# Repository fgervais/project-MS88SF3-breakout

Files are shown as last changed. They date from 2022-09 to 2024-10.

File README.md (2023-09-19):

# MS88SF3 Breakout Board

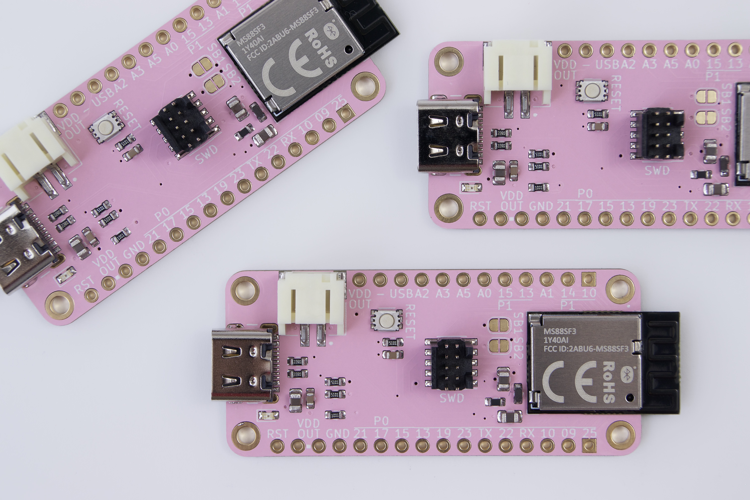
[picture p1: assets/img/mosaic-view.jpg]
Overview

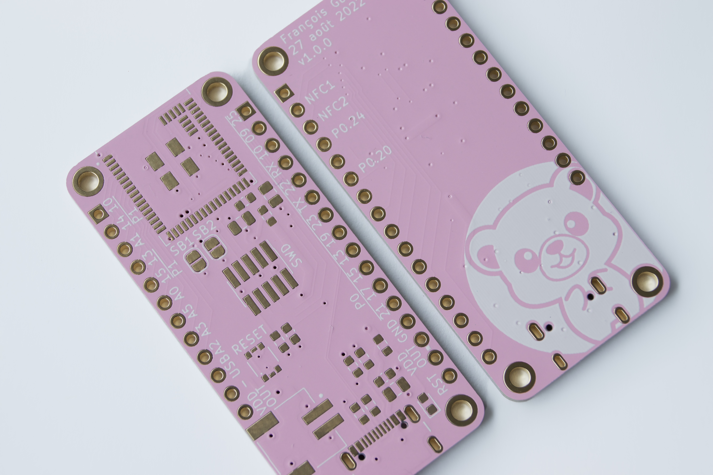
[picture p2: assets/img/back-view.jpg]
PCB


## Objective

Try out the nRF52840 module from Minew.

## Power Consumption

### Sleep - Full RAM retention - GPIO wake-up

Average: 2.78 μA

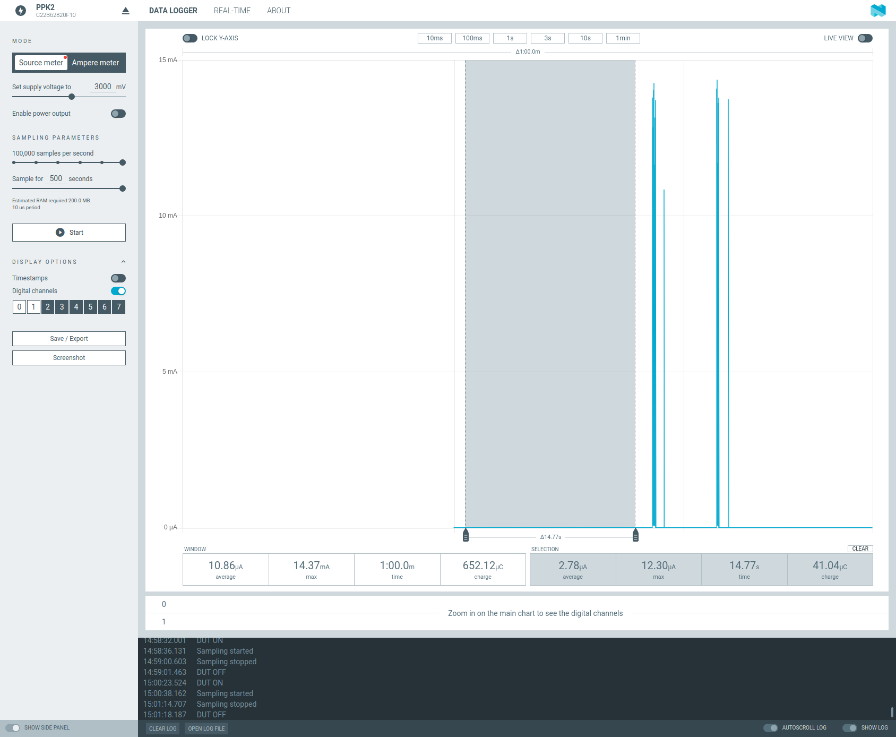
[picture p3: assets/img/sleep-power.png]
Sleep Power


## Price

## PCB

## BOM

### Firmware

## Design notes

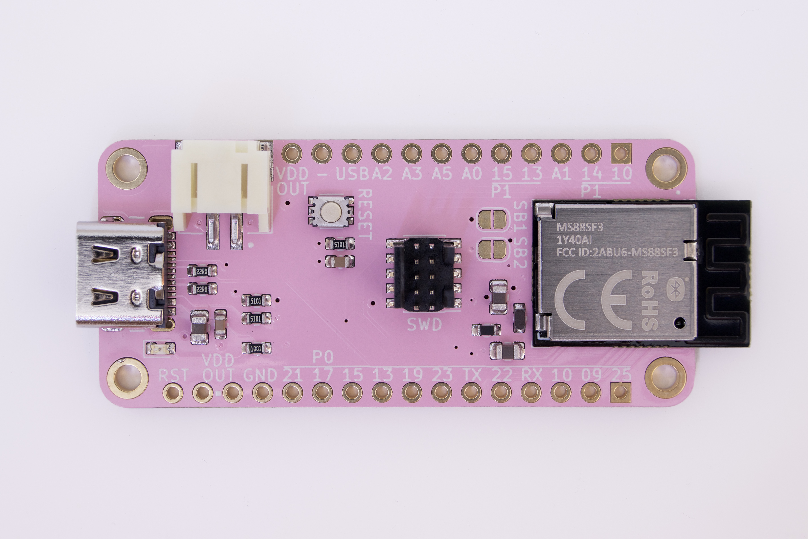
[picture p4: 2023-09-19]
assets/img/single-top-view.jpg

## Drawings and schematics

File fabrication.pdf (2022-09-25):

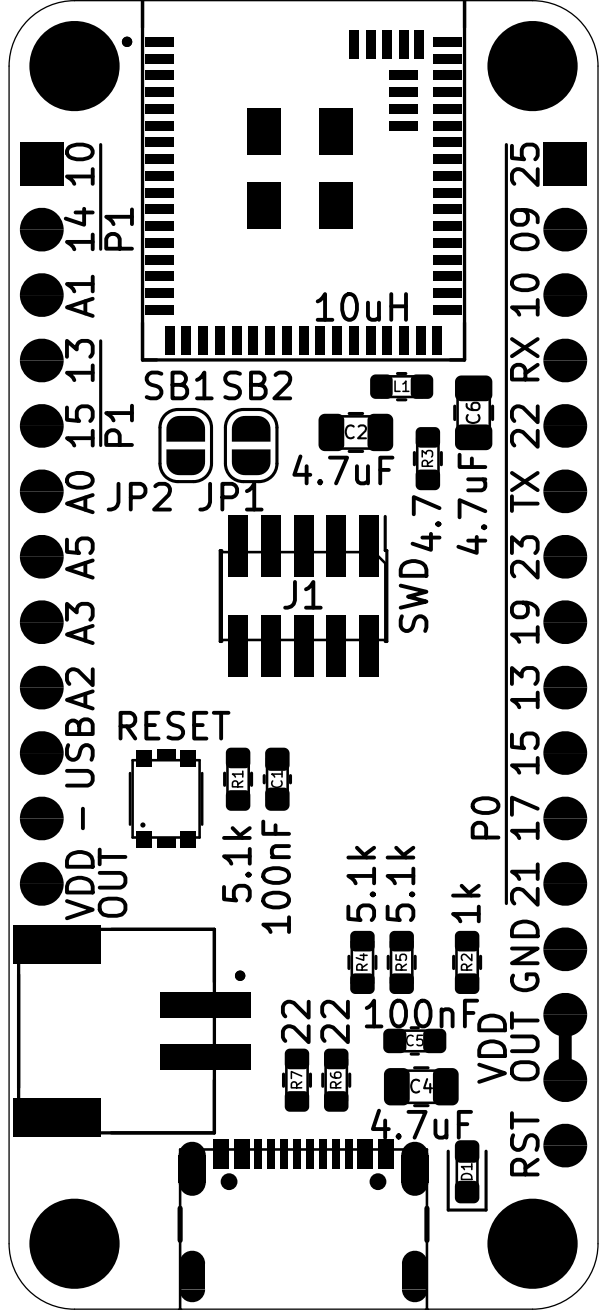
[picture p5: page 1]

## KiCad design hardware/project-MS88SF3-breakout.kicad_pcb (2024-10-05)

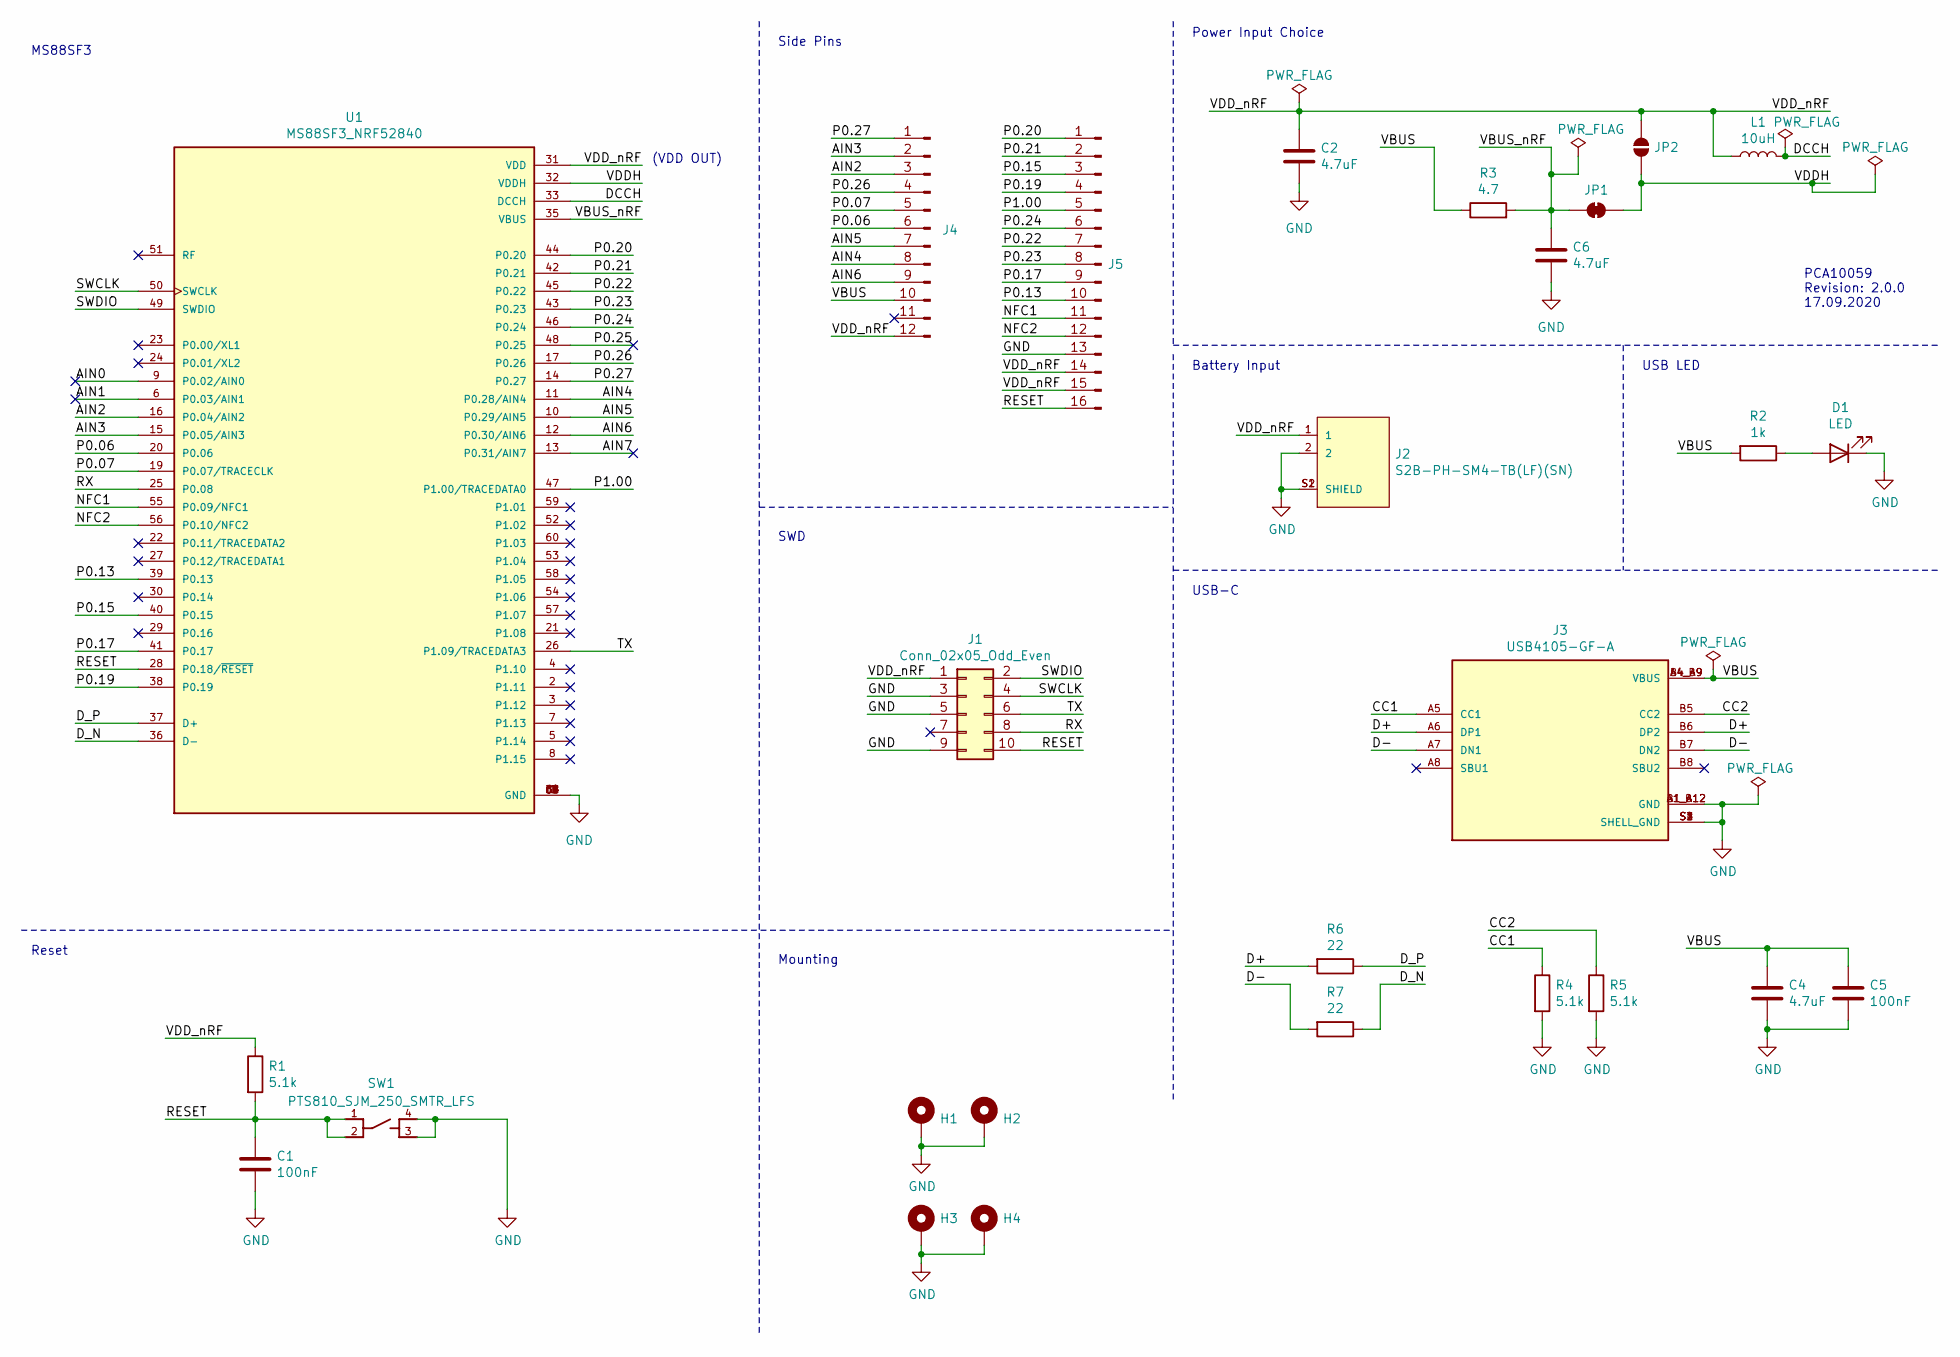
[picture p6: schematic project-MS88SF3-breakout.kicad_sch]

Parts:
C1, C5: 100nF; C_0603_1608Metric
C2, C4, C6: 4.7uF; C_0805_2012Metric
D1: LED; LED_0603_1608Metric
H1, H2, H3, H4: MountingHole_Pad; MountingHole_2.2mm_M2_ISO7380_Pad
J1: Conn_02x05_Odd_Even; PinHeader_2x05_P1.27mm_Vertical_SMD
J2: S2B-PH-SM4-TB(LF)(SN); JST_S2B-PH-SM4-TB(LF)(SN)
J3: USB4105-GF-A; GCT_USB4105-GF-A; PARTREV A3
J4: Conn_01x12_Pin; PinHeader_1x12_P2.54mm_Vertical
J5: Conn_01x16_Pin; PinHeader_1x16_P2.54mm_Vertical
JP1: SolderJumper_2_Bridged; SolderJumper-2_P1.3mm_Bridged_RoundedPad1.0x1.5mm
JP2: SolderJumper_2_Open; SolderJumper-2_P1.3mm_Open_RoundedPad1.0x1.5mm
L1: 10uH; L_0603_1608Metric
R1, R4, R5: 5.1k; R_0603_1608Metric
R2: 1k; R_0603_1608Metric
R3: 4.7; R_0603_1608Metric
R6, R7: 22; R_0603_1608Metric
SW1: PTS810_SJM_250_SMTR_LFS; SW_PTS810_SJM_250_SMTR_LFS; DigiKey_Part_Number CKN10502TR-ND
U1: MS88SF3_NRF52840; MODULE_MS88SF3_NRF52840; PARTREV V1.1

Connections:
/AIN0: U1.9 (P0.02/AIN0)
/AIN1: U1.6 (P0.03/AIN1)
/AIN2: J4.3, U1.16 (P0.04/AIN2)
/AIN3: J4.2, U1.15 (P0.05/AIN3)
/AIN4: J4.8, U1.11 (P0.28/AIN4)
/AIN5: J4.7, U1.10 (P0.29/AIN5)
/AIN6: J4.9, U1.12 (P0.30/AIN6)
/AIN7: U1.13 (P0.31/AIN7)
/CC1: J3.A5 (CC1), R4.1
/CC2: J3.B5 (CC2), R5.1
/D+: J3.A6 (DP1), J3.B6 (DP2), R6.2
/D-: J3.A7 (DN1), J3.B7 (DN2), R7.2
/DCCH: L1.2, U1.33 (DCCH)
/D_N: R7.1, U1.36 (D-)
/D_P: R6.1, U1.37 (D+)
/NFC1: J5.11, U1.55 (P0.09/NFC1)
/NFC2: J5.12, U1.56 (P0.10/NFC2)
/P0.06: J4.6, U1.20 (P0.06)
/P0.07: J4.5, U1.19 (P0.07/TRACECLK)
/P0.13: J5.10, U1.39 (P0.13)
/P0.15: J5.3, U1.40 (P0.15)
/P0.17: J5.9, U1.41 (P0.17)
/P0.19: J5.4, U1.38 (P0.19)
/P0.20: J5.1, U1.44 (P0.20)
/P0.21: J5.2, U1.42 (P0.21)
/P0.22: J5.7, U1.45 (P0.22)
/P0.23: J5.8, U1.43 (P0.23)
/P0.24: J5.6, U1.46 (P0.24)
/P0.25: U1.48 (P0.25)
/P0.26: J4.4, U1.17 (P0.26)
/P0.27: J4.1, U1.14 (P0.27)
/P1.00: J5.5, U1.47 (P1.00/TRACEDATA0)
/RESET: C1.1, J1.10, J5.16, R1.2, SW1.1, SW1.2, U1.28 (P0.18/~RESET)
/RX: J1.8, U1.25 (P0.08)
/SWCLK: J1.4, U1.50 (SWCLK)
/SWDIO: J1.2, U1.49 (SWDIO)
/TX: J1.6, U1.26 (P1.09/TRACEDATA3)
/VBUS: C4.1, C5.1, J3.A4_B9 (VBUS), J3.B4_A9 (VBUS), J4.10, R2.2, R3.1
/VBUS_nRF: C6.1, JP1.1 (A), R3.2, U1.35 (VBUS)
/VDDH: JP1.2 (B), JP2.2 (B), U1.32 (VDDH)
/VDD_nRF: C2.1, J1.1, J2.1, J4.12, J5.14, J5.15, JP2.1 (A), L1.1, R1.1, U1.31 (VDD)
GND: C1.2, C2.2, C4.2, C5.2, C6.2, D1.1 (K), H1.1, H2.1, H3.1, H4.1, J1.3, J1.5, J1.9, J2.2, J2.S1 (SHIELD), J2.S2 (SHIELD), J3.A1_B12 (GND), J3.B1_A12 (GND), J3.S1 (SHELL_GND), J3.S2 (SHELL_GND), J3.S3 (SHELL_GND), J3.S4 (SHELL_GND), J5.13, R4.2, R5.2, SW1.3, SW1.4, U1.1 (GND), U1.18 (GND), U1.34 (GND), U1.61 (GND), U1.62 (GND), U1.63 (GND), U1.64 (GND)
unnamed: D1.2 (A), R2.1

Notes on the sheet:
USB LED
Side Pins
SWD
Mounting
PCA10059 Revision: 2.0.0 17.09.2020
Power Input Choice
Battery Input
Reset
USB-C
(VDD OUT)
MS88SF3

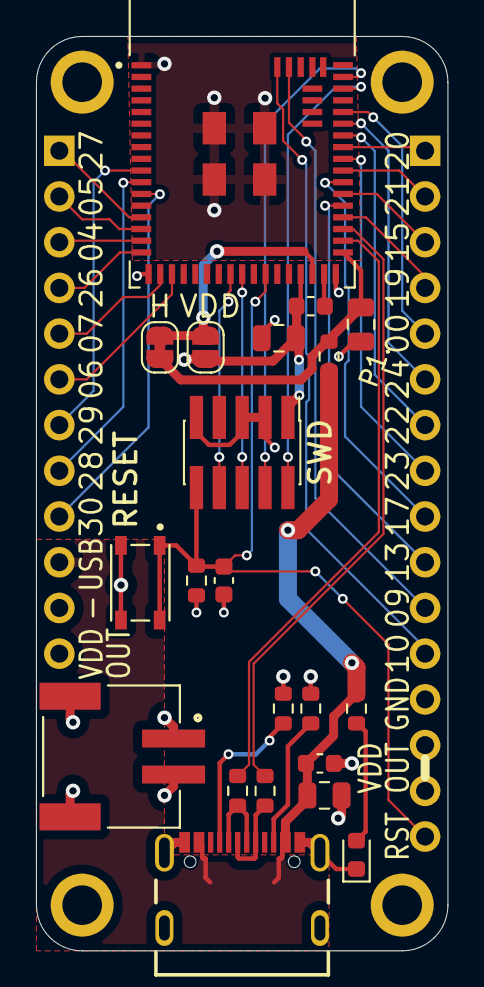
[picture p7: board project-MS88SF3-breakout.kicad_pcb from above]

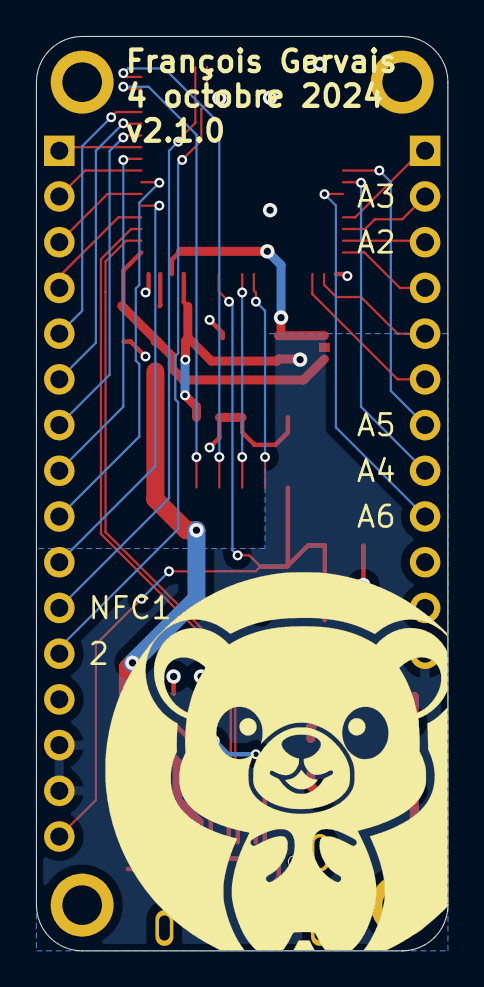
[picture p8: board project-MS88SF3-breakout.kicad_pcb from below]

Board: 4 copper layers, 22.9 x 50.8 mm, 28 parts (3 on the bottom side), 39 nets.

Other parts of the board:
Ref**: Val**; bear-body_silk_16x16

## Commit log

2022-07-01 Blank project
    [project-MS88SF3-breakout.kicad_pcb, project-MS88SF3-breakout.sch]
2022-07-02 Add the MS88SF3 symbol
    [project-MS88SF3-breakout.sch]
2022-08-22 Most components added to schematic
    [project-MS88SF3-breakout.sch]
2022-08-22 First placement
    [project-MS88SF3-breakout.kicad_pcb, project-MS88SF3-breakout.sch]
2022-08-24 Add wires to schematic
    [project-MS88SF3-breakout.sch]
2022-08-25 Make it a feather shape
    [project-MS88SF3-breakout.kicad_pcb, project-MS88SF3-breakout.sch]
2022-08-25 Change the MS88SF3 module to the nRF52840
    [project-MS88SF3-breakout.kicad_pcb, project-MS88SF3-breakout.sch]
2022-08-26 Everything connected
    [project-MS88SF3-breakout.kicad_pcb, project-MS88SF3-breakout.sch]
2022-08-26 Half routing done
    [project-MS88SF3-breakout.kicad_pcb, project-MS88SF3-breakout.sch]
2022-08-27 USB route
    [project-MS88SF3-breakout.kicad_pcb, project-MS88SF3-breakout.sch]
2022-08-27 Routing done
    [project-MS88SF3-breakout.kicad_pcb, project-MS88SF3-breakout.sch]
2022-08-28 Clean up schematic
    [project-MS88SF3-breakout.kicad_pcb, project-MS88SF3-breakout.sch]
2022-08-29 Ground fill under the module
    [project-MS88SF3-breakout.kicad_pcb]
2022-09-02 Add the bear on the bottom
    [project-MS88SF3-breakout.kicad_pcb]
2022-09-03 Show other layers
    [project-MS88SF3-breakout.kicad_pcb]
2022-09-03 Add gerber files
    [project-MS88SF3-breakout-B_Cu.gbr, project-MS88SF3-breakout-B_Mask.gbr, project-MS88SF3-breakout-B_Paste.gbr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]
2022-09-05 Generate gerbers
    [project-MS88SF3-breakout.kicad_pcb]
2022-09-25 Create fab sheet
    [project-MS88SF3-breakout.kicad_pcb]
2022-09-30 Select different layers
    [project-MS88SF3-breakout.kicad_pcb]
2022-10-02 Add images of board
2022-10-26 Remove unused vias on VBUS fill
    [project-MS88SF3-breakout.kicad_pcb]
2022-10-26 Remove version on silk
    [project-MS88SF3-breakout.kicad_pcb]
2022-10-26 Upgrade ground fill under module
    [project-MS88SF3-breakout.kicad_pcb]
2022-10-30 Add sleep power information (2.78uA)
2022-10-30 Add power value
2023-02-25 Add edge cut svg
2024-04-26 New project format
    [project-MS88SF3-breakout.kicad_sch]
2024-04-26 Update obsolete connectors
    [project-MS88SF3-breakout.kicad_sch]
2024-04-26 Unrescue pwr_flag and gnd
    [project-MS88SF3-breakout.kicad_sch]
2024-04-26 Fix ERC error
    [project-MS88SF3-breakout.kicad_sch]
2024-04-26 Change reset button
    [project-MS88SF3-breakout.kicad_sch]
2024-04-26 User SolderJumper-2 footprint without center soldermask
    [project-MS88SF3-breakout.kicad_sch]
2024-04-26 Move TX to SWO
    [project-MS88SF3-breakout.kicad_sch]
2024-04-27 Change header RX/TX to gpios
    [project-MS88SF3-breakout.kicad_sch]
2024-04-27 Change swd RX/TX to easier pins to route
    [project-MS88SF3-breakout.kicad_sch]
2024-04-27 Open pcb and save
    [project-MS88SF3-breakout.kicad_pcb]
2024-04-27 Fill pours and run DRC
    [project-MS88SF3-breakout.kicad_pcb]
2024-04-27 Update pcb from schematic
    [project-MS88SF3-breakout.kicad_pcb]
2024-04-27 Remove unused traces
    [project-MS88SF3-breakout.kicad_pcb]
2024-04-28 Change 12/16 pin header footprint
    [project-MS88SF3-breakout.kicad_sch]
2024-04-28 Update pin headers from schematic
    [project-MS88SF3-breakout.kicad_pcb]
2024-04-28 Place new button
    [project-MS88SF3-breakout.kicad_pcb]
2024-04-28 Change old RX/TX pin silkscreen
    [project-MS88SF3-breakout.kicad_pcb]
2024-04-28 Send all alternate silkscreen to the back
    [project-MS88SF3-breakout.kicad_pcb]
2024-04-28 Route all nets
    [project-MS88SF3-breakout.kicad_pcb]
2024-04-28 Bring back the panda
    [project-MS88SF3-breakout.kicad_pcb]
2024-04-28 Add the gerbers zip file
    I think this is the zip I used to have the pink boards made.
2024-04-28 Run schematic ERC
2024-04-28 Update date silkscreen
    [project-MS88SF3-breakout.kicad_pcb]
2024-04-28 Make part of VDDH trace smaller
    [project-MS88SF3-breakout.kicad_pcb]
2024-04-28 Add the silkscreen version of the previous commit
    [project-MS88SF3-breakout.kicad_pcb]
2024-04-28 Remove obsolete files
    [project-MS88SF3-breakout.sch]
2024-04-29 Remove solder mask expansion from button footprint
    [project-MS88SF3-breakout.kicad_pcb]
2024-04-29 Make smoother VBUS pad entry
    [project-MS88SF3-breakout.kicad_pcb]
2024-04-29 Update the solder jumpers
    [project-MS88SF3-breakout.kicad_pcb]
2024-04-29 Remove v1 gerbers
    [project-MS88SF3-breakout-B_Cu.gbr, project-MS88SF3-breakout-B_Mask.gbr, project-MS88SF3-breakout-B_Paste.gbr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]
2024-04-29 Update version on silkscreen
    [project-MS88SF3-breakout.kicad_pcb]
2024-10-03 Save with current kicad version
2024-10-03 Update half the pins in the schematic
    [project-MS88SF3-breakout.kicad_sch]
2024-10-04 Finish routing
    [project-MS88SF3-breakout.kicad_pcb, project-MS88SF3-breakout.kicad_sch]
2024-10-05 Finish back side silkscreen
    [project-MS88SF3-breakout.kicad_pcb]
2024-10-05 Finish front side silkscreen
    [project-MS88SF3-breakout.kicad_pcb]
